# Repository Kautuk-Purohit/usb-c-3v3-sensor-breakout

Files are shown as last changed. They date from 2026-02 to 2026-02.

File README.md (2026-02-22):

# KiCad PCB Project

A fabrication ready PCB designed as a portfolio project.  
Includes a full schematic and PCB layout, verified with ERC (Electrical Rules Check) and DRC (Design Rules Check), and validated Gerbers and drills in Gerber Viewer.

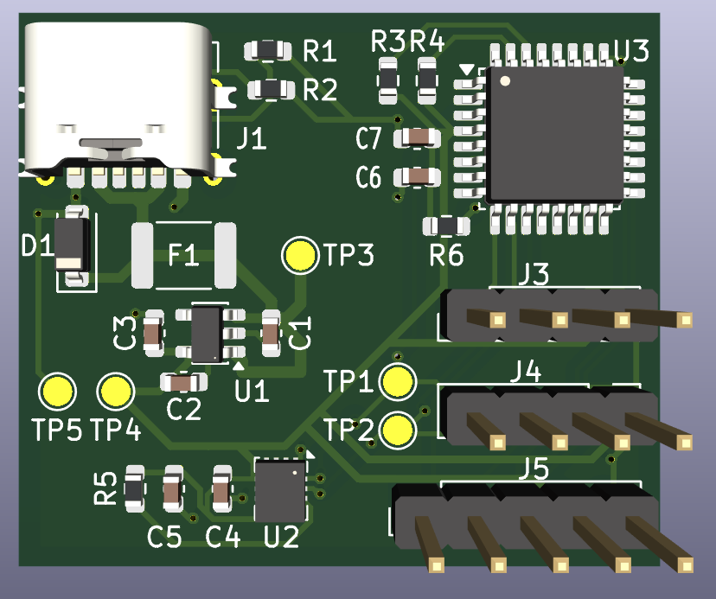
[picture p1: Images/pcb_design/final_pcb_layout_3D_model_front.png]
PCB 3D View


---

## Table of Contents
- [Overview](#overview)
- [Key Features](#key-features)
- [Project Status](#project-status)
- [Repo Structure](#repo-structure)
- [Verification](#verification)
- [Manufacturing Outputs](#manufacturing-outputs)
- [How to Open](#how-to-open)
- [Key Images](#images)
- [Next Improvements](#next-improvements)

---

## Overview
This project demonstrates an end to end PCB workflow:

schematic design → layout and routing → design rule checks → manufacturing outputs

The goal is to show practical board design skills (power, interfaces, layout, manufacturability) 

---

## Key Features
- USB power input with on board 3.3V regulation
- Microcontroller based system design
- I2C (Inter Integrated Circuit) sensor bus (IMU)
- Labeled connectors and test points for bring up
- Ground plane implemented
- Manufacturing package generated (Gerbers + PTH and NPTH drills)
- BOM and pick and place exported for assembly readiness

---

## Project Status
- [x] Placement and routing complete
- [x] Ground plane set
- [x] ERC clean
- [x] DRC clean
- [x] 3D view checked for footprint consistency
- [x] Gerbers generated
- [x] Drill files generated (PTH + NPTH)
- [x] Gerbers and drills verified in Gerber Viewer
- [X] BOM committed
- [X] Pick and place committed

---

## Repo Structure
```text
.
├── kicad/                     # KiCad schematic + PCB
├── manufacturing/
│   ├── gerbers/               # plotted Gerbers
│   ├── drill/                 # Excellon drills (PTH + NPTH)
│   ├── bom/                   # BOM exports
│   ├── assembly/              # pick and place / position outputs
│   └── release/               # upload ready ZIP(s)
└── images/                    
│   ├── manufacturing/         # Manufacturing related pictures
│   ├── pcb_design/            # PCB Design pictures
│   ├── schematic/             # Schematic related pictures
```
---

## Verification
- ERC (Electrical Rules Check): clean
- DRC (Design Rules Check): clean
- 3D Viewer: checked for footprint consistency
- Gerber Viewer: verified copper, mask, silkscreen, outline, and drill alignment (PTH + NPTH)

---

## Manufacturing Outputs
### Fabrication package (upload ready)
[RELEASE FILE](manufacturing/release/PCB_RELEASE_GERBER_DRILL.zip)

### Assembly data
- [BOM](manufacturing/bom/usb_c_sensor_breakout.csv)
- [Pick and Place POS Files](manufacturing/assembly)

---

## How to Open
1. Install KiCad (project created in KiCad 9.0).
2. Open the project in `kicad/`.
3. Review:
   - Schematic (`.kicad_sch`)
   - PCB layout (`.kicad_pcb`)
   - 3D Viewer
4. Manufacturing outputs are in `manufacturing/`.

---

## Images

### PCB 3D front:
PCB 3D Front

### PCB 3D back:
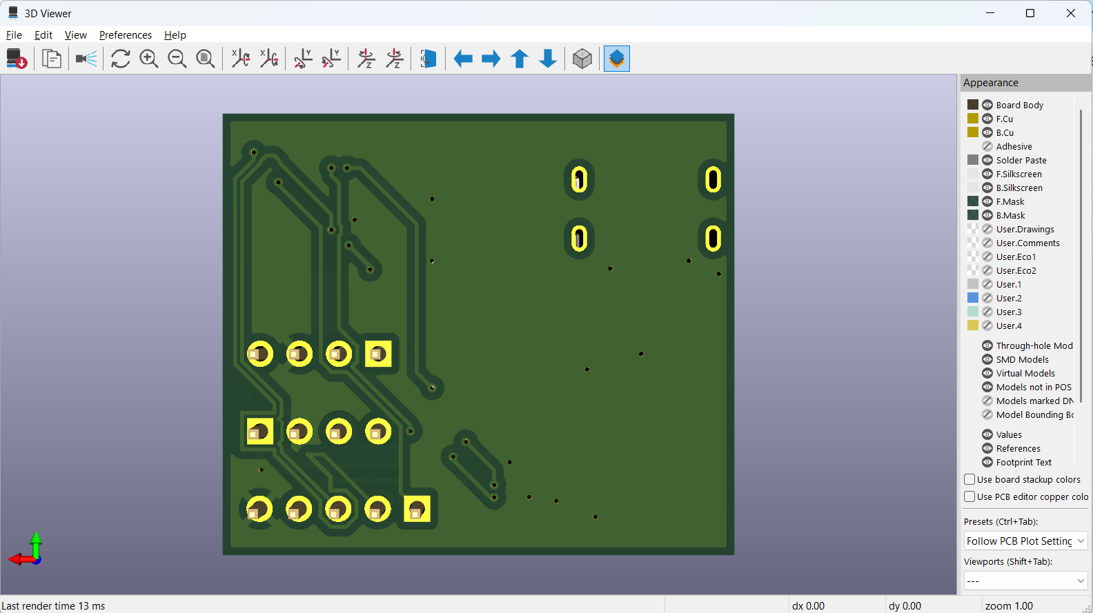
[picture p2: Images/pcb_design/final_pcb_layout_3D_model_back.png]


### PCB Final Layout: 
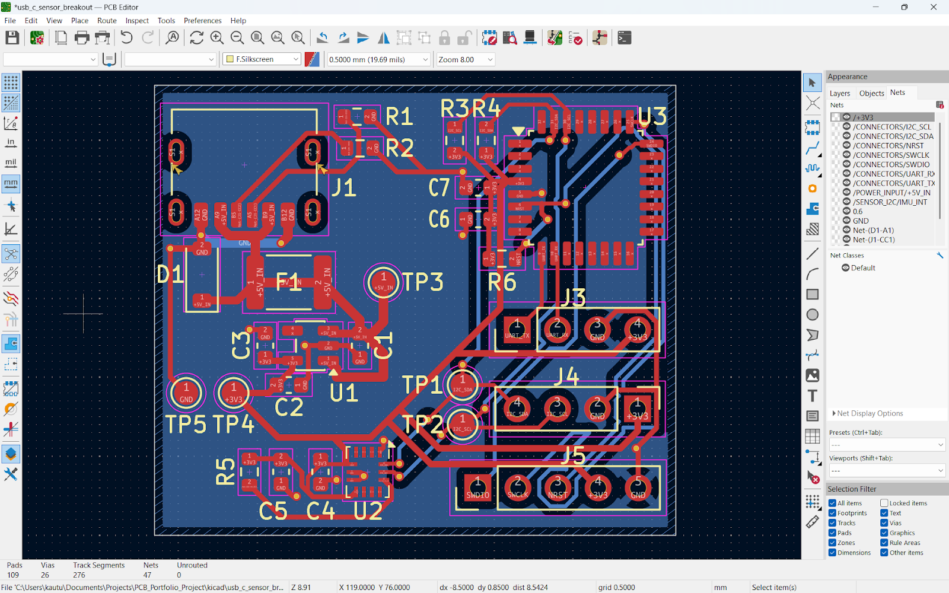
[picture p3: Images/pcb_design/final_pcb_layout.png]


### Gerber overlay: 
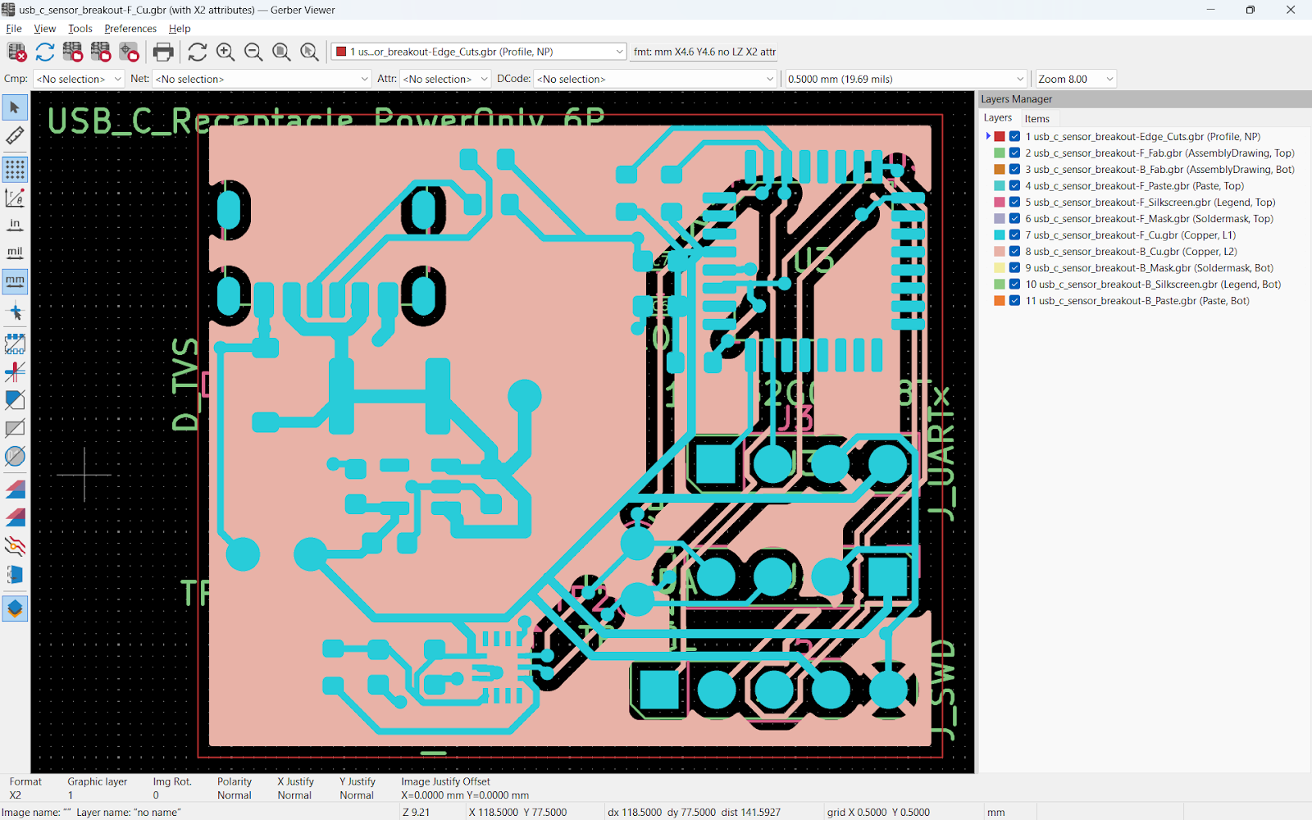
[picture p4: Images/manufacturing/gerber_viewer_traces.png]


### Drill overlay (PTH + NPTH): 
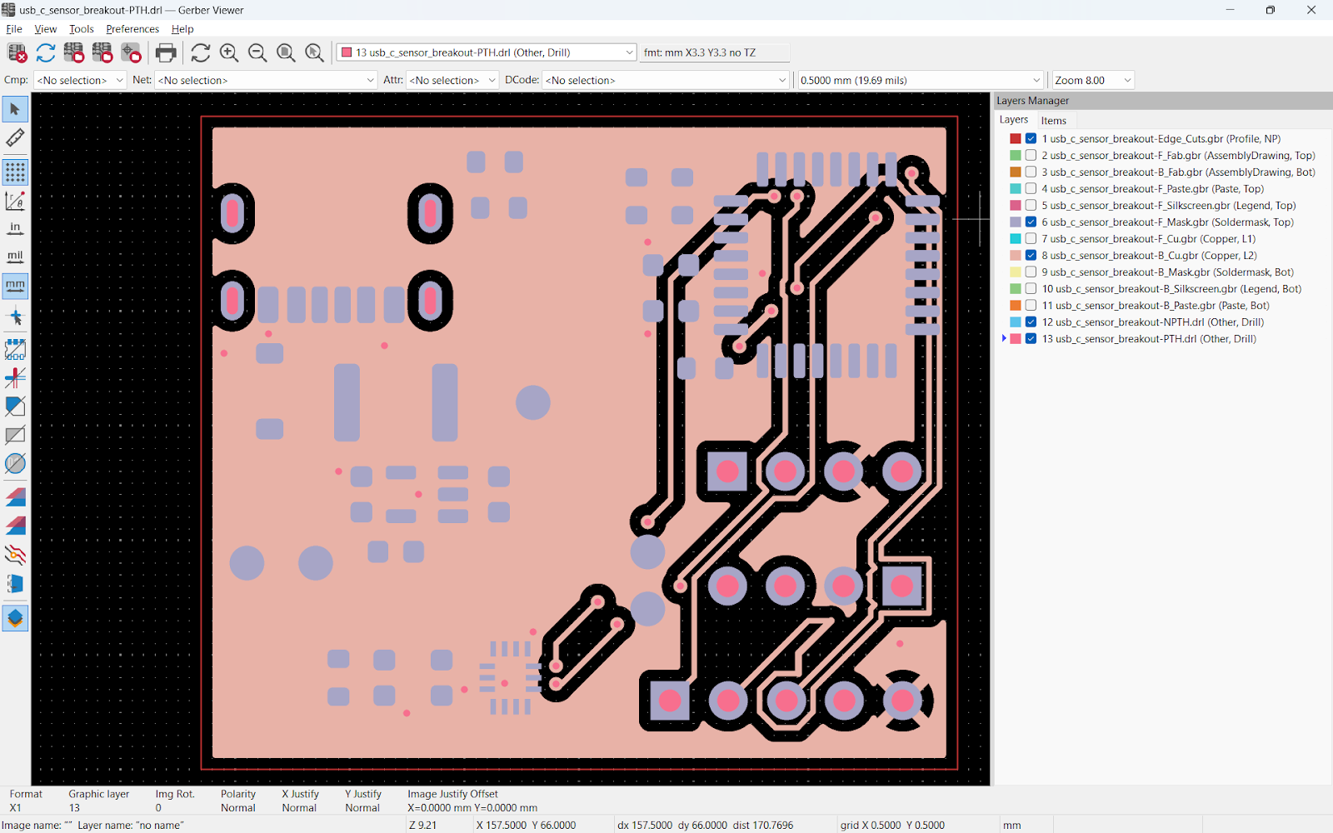
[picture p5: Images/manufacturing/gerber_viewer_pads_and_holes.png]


---

## Next Improvements
In a future revision:
- Add fiducials
- Add additional ESD protection (eg. for external connectors)
- Improve silkscreen placement and reference readability
- Adding NPTH drills (mounting holes) for realistic usage

---

## License
All Rights Reserved.

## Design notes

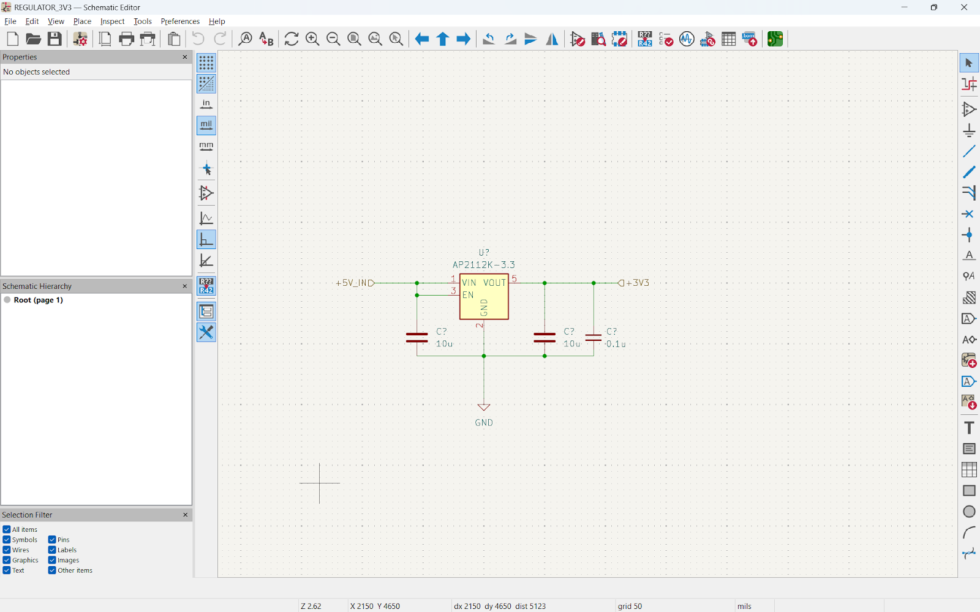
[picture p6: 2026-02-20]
Images/schematic/regulator_iteration1.png

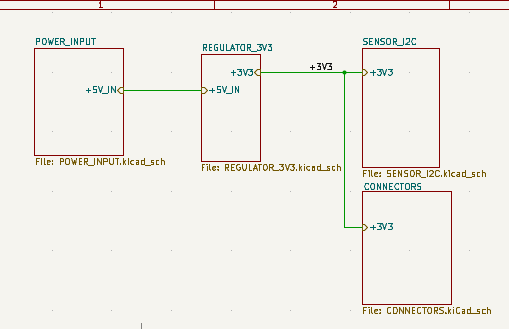
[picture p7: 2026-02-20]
Images/schematic/top_level_iteration1.png

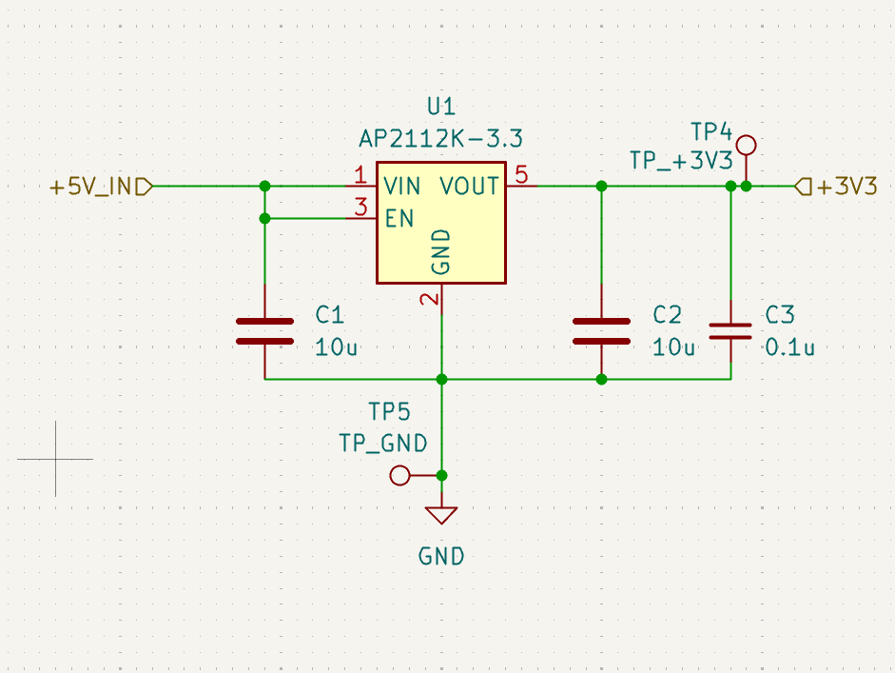
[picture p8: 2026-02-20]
Images/schematic/final_regulator_schematic.png

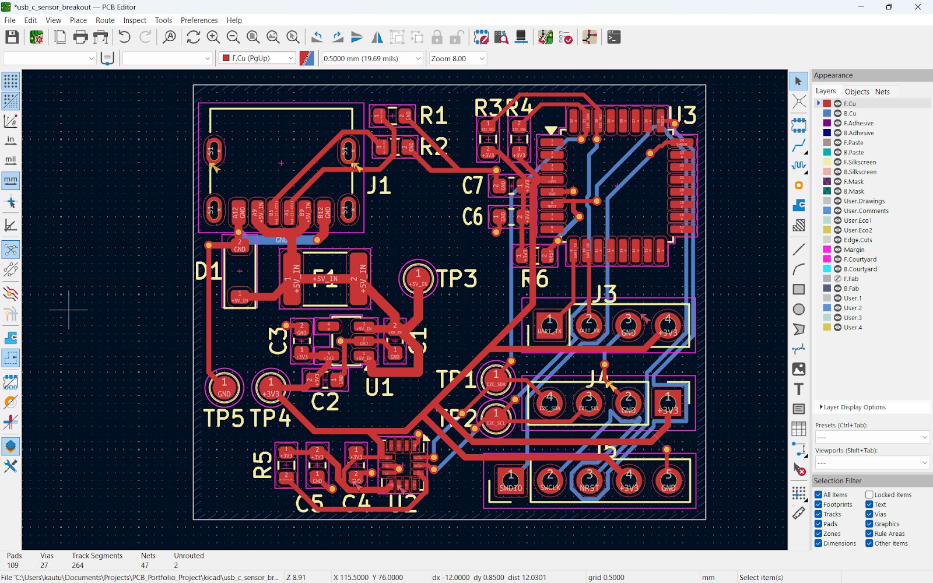
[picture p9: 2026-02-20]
Images/pcb_design/iteration1_traces.png

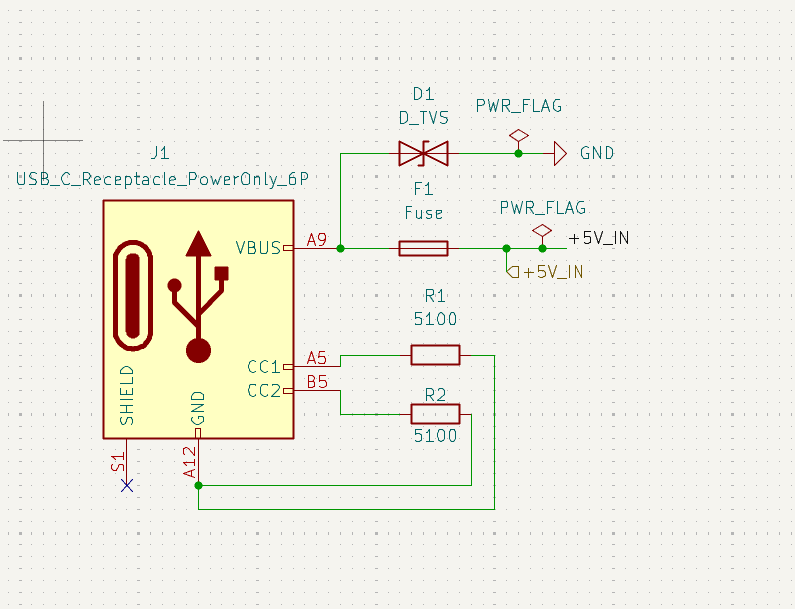
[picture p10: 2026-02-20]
Images/schematic/power_input_iteration1.png

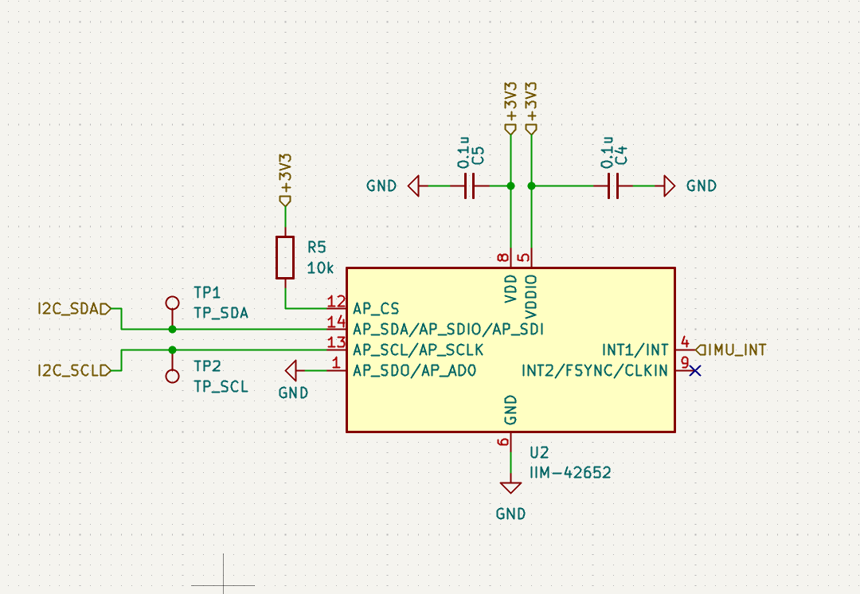
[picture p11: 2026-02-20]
Images/schematic/final_sensor_schematic.png

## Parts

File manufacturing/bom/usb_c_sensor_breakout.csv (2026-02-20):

Reference | Qty | Value | DNP | Exclude from BOM | Exclude from Board | Footprint | Datasheet
C1,C2,C6 | 3 | 10u |  |  |  | Capacitor_SMD:C_0603_1608Metric | ~
C3,C4,C5,C7 | 4 | 0.1u |  |  |  | Capacitor_SMD:C_0603_1608Metric | ~
D1 | 1 | D_TVS |  |  |  | Diode_SMD:D_SOD-123 | ~
F1 | 1 | Fuse |  |  |  | Fuse:Fuse_1812_4532Metric | ~
J1 | 1 | USB_C_Receptacle_PowerOnly_6P |  |  |  | Connector_USB:USB_C_Receptacle_HRO_TYPE-C-31-M-17 | https://www.usb.org/sites/default/files/documents/usb_type-c.zip
J3 | 1 | J_UART |  |  |  | Connector_PinHeader_2.54mm:PinHeader_1x04_P2.54mm_Vertical | ~
J4 | 1 | J_I2C_EXP |  |  |  | Connector_PinHeader_2.54mm:PinHeader_1x04_P2.54mm_Vertical | ~
J5 | 1 | J_SWD |  |  |  | Connector_PinHeader_2.54mm:PinHeader_1x05_P2.54mm_Vertical | ~
R1,R2 | 2 | 5100 |  |  |  | Resistor_SMD:R_0603_1608Metric | ~
R3,R4 | 2 | 4.7k |  |  |  | Resistor_SMD:R_0603_1608Metric | ~
R5,R6 | 2 | 10k |  |  |  | Resistor_SMD:R_0603_1608Metric | ~
TP1 | 1 | TP_SDA |  |  |  | TestPoint:TestPoint_Pad_D1.5mm | ~
TP2 | 1 | TP_SCL |  |  |  | TestPoint:TestPoint_Pad_D1.5mm | ~
TP3 | 1 | TP_+5V_IN |  |  |  | TestPoint:TestPoint_Pad_D1.5mm | ~
TP4 | 1 | TP_+3V3 |  |  |  | TestPoint:TestPoint_Pad_D1.5mm | ~
TP5 | 1 | TP_GND |  |  |  | TestPoint:TestPoint_Pad_D1.5mm | ~
U1 | 1 | AP2112K-3.3 |  |  |  | Package_TO_SOT_SMD:SOT-23-5 | https://www.diodes.com/assets/Datasheets/AP2112.pdf
U2 | 1 | IIM-42652 |  |  |  | Package_LGA:Bosch_LGA-14_3x2.5mm_P0.5mm | https://invensense.tdk.com/wp-content/uploads/2021/01/ds-000440_iim-42652-datasheet.pdf
U3 | 1 | STM32G031K8Tx |  |  |  | Package_QFP:LQFP-32_7x7mm_P0.8mm | https://www.st.com/resource/en/datasheet/stm32g031k8.pdf

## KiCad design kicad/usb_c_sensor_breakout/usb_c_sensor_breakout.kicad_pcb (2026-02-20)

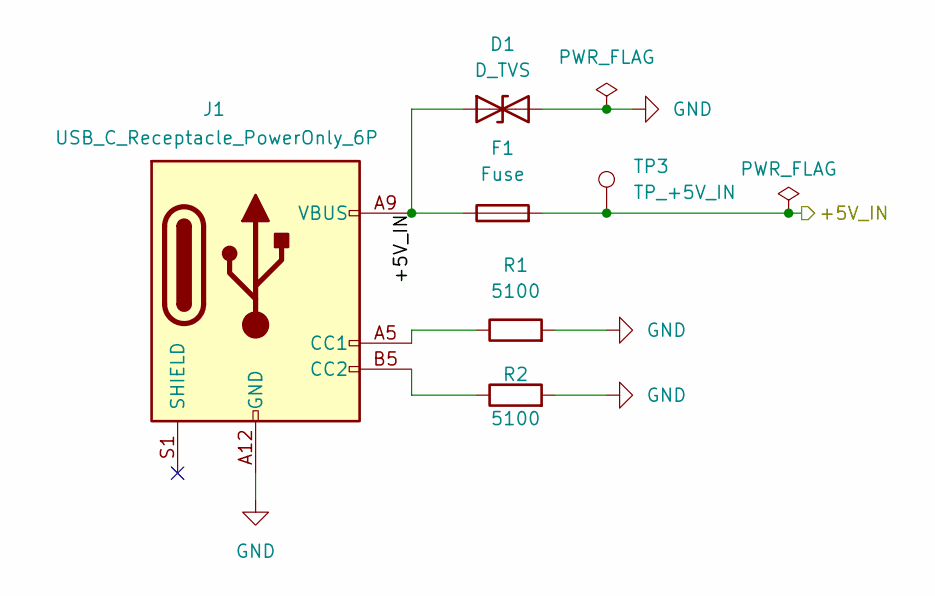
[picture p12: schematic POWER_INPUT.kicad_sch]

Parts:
D1: D_TVS; D_SOD-123
F1: Fuse; Fuse_1812_4532Metric
J1: USB_C_Receptacle_PowerOnly_6P; USB_C_Receptacle_HRO_TYPE-C-31-M-17
R1, R2: 5100; R_0603_1608Metric
TP3: TP_+5V_IN; TestPoint_Pad_D1.5mm

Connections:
/POWER_INPUT/+5V_IN: D1.1 (A1), F1.1, F1.2, J1.A9 (VBUS), J1.B9 (VBUS), TP3.1; also elsewhere on the board
GND: D1.2 (A2), J1.A12 (GND), J1.B12 (GND), R1.2, R2.2; also elsewhere on the board
unnamed: J1.A5 (CC1), R1.1
unnamed: J1.B5 (CC2), R2.1

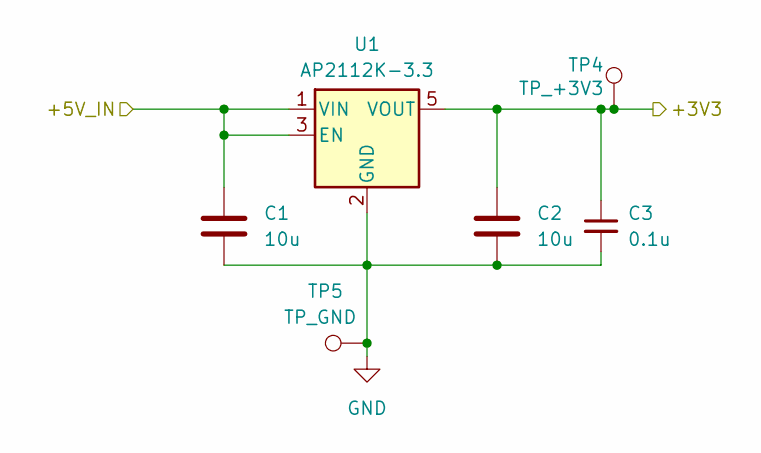
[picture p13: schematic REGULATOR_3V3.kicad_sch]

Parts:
C1, C2: 10u; C_0603_1608Metric
C3: 0.1u; C_0603_1608Metric
TP4: TP_+3V3; TestPoint_Pad_D1.5mm
TP5: TP_GND; TestPoint_Pad_D1.5mm
U1: AP2112K-3.3; SOT-23-5

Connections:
/+3V3: C2.2, C3.1, TP4.1, U1.5 (VOUT); also elsewhere on the board
/POWER_INPUT/+5V_IN: C1.2, U1.1 (VIN), U1.3 (EN); also elsewhere on the board
GND: C1.1, C2.1, C3.2, TP5.1, U1.2 (GND); also elsewhere on the board

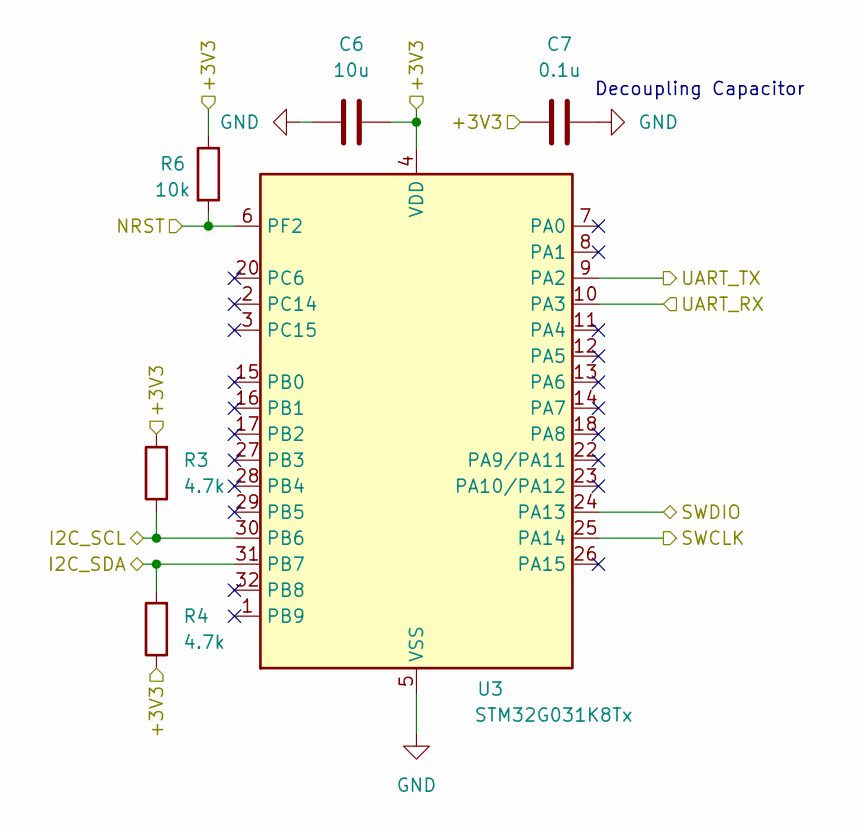
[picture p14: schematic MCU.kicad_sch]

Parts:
C6: 10u; C_0603_1608Metric
C7: 0.1u; C_0603_1608Metric
R3, R4: 4.7k; R_0603_1608Metric
R6: 10k; R_0603_1608Metric
U3: STM32G031K8Tx; LQFP-32_7x7mm_P0.8mm

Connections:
/+3V3: C6.2, C7.1, R3.2, R4.1, R6.1, U3.4 (VDD); also elsewhere on the board
/CONNECTORS/I2C_SCL: R3.1, U3.30 (PB6); also elsewhere on the board
/CONNECTORS/I2C_SDA: R4.2, U3.31 (PB7); also elsewhere on the board
/CONNECTORS/NRST: R6.2, U3.6 (PF2); also elsewhere on the board
/CONNECTORS/SWCLK: U3.25 (PA14); also elsewhere on the board
/CONNECTORS/SWDIO: U3.24 (PA13); also elsewhere on the board
/CONNECTORS/UART_RX: U3.10 (PA3); also elsewhere on the board
/CONNECTORS/UART_TX: U3.9 (PA2); also elsewhere on the board
GND: C6.1, C7.2, U3.5 (VSS); also elsewhere on the board

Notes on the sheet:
Decoupling Capacitor

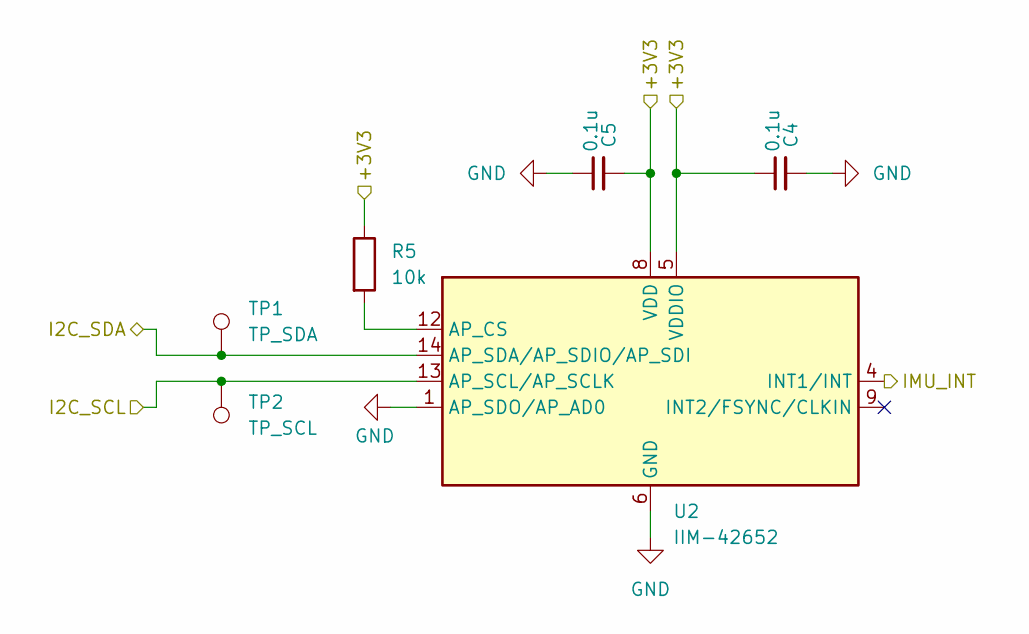
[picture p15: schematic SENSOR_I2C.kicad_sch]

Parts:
C4, C5: 0.1u; C_0603_1608Metric
R5: 10k; R_0603_1608Metric
TP1: TP_SDA; TestPoint_Pad_D1.5mm
TP2: TP_SCL; TestPoint_Pad_D1.5mm
U2: IIM-42652; Bosch_LGA-14_3x2.5mm_P0.5mm

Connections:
/+3V3: C4.1, C5.2, R5.1, U2.5 (VDDIO), U2.8 (VDD); also elsewhere on the board
/CONNECTORS/I2C_SCL: TP2.1, U2.13 (AP_SCL/AP_SCLK); also elsewhere on the board
/CONNECTORS/I2C_SDA: TP1.1, U2.14 (AP_SDA/AP_SDIO/AP_SDI); also elsewhere on the board
/SENSOR_I2C/IMU_INT: U2.4 (INT1/INT)
GND: C4.2, C5.1, U2.1 (AP_SDO/AP_AD0), U2.6 (GND), U2.7 (GND); also elsewhere on the board
unnamed: R5.2, U2.12 (AP_CS)

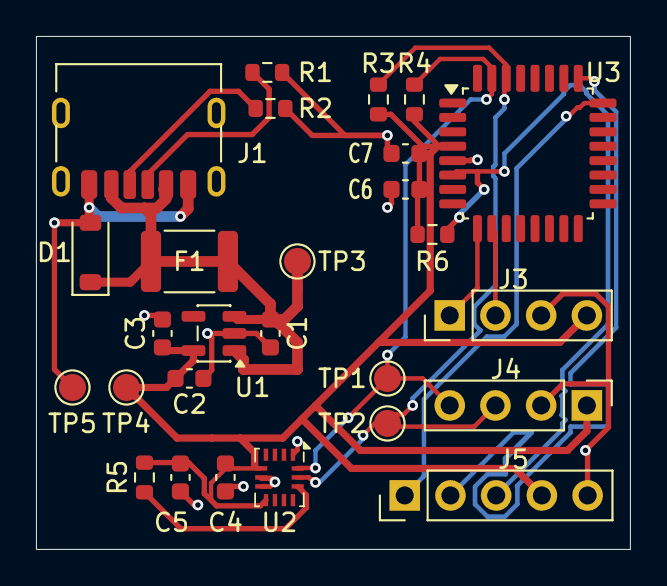
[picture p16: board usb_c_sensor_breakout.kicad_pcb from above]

Board: 2 copper layers, 33.0 x 28.5 mm, 27 parts (0 on the bottom side), 13 nets.

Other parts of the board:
J3: J_UART; PinHeader_1x04_P2.54mm_Vertical
J4: J_I2C_EXP; PinHeader_1x04_P2.54mm_Vertical
J5: J_SWD; PinHeader_1x05_P2.54mm_Vertical

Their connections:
/+3V3: J3.4, J4.1, J5.4; also elsewhere on the board
/CONNECTORS/I2C_SCL: J4.3; also elsewhere on the board
/CONNECTORS/I2C_SDA: J4.4; also elsewhere on the board
/CONNECTORS/NRST: J5.3; also elsewhere on the board
/CONNECTORS/SWCLK: J5.2; also elsewhere on the board
/CONNECTORS/SWDIO: J5.1; also elsewhere on the board
/CONNECTORS/UART_RX: J3.2; also elsewhere on the board
/CONNECTORS/UART_TX: J3.1; also elsewhere on the board
GND: J3.3, J4.2, J5.5; also elsewhere on the board

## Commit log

2026-02-05 Day 0: project structure and KiCad project
    [usb_c_sensor_breakout.kicad_pcb, usb_c_sensor_breakout.kicad_sch]
2026-02-14 commit2: usbc + regulator + i2c pullups + sensor header + testpoint
    [CONNECTORS.kicad_sch, POWER_INPUT.kicad_sch, REGULATOR_3V3.kicad_sch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]
2026-02-15 Commit3: Regulators + Top-level + I2C sensor upgrade
    [CONNECTORS.kicad_sch, POWER_INPUT.kicad_sch, REGULATOR_3V3.kicad_sch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]
2026-02-15 Commit 4: Updated annotation + footprints
    [CONNECTORS.kicad_sch, POWER_INPUT.kicad_sch, REGULATOR_3V3.kicad_sch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]
2026-02-15 Commit 5: MCU + Final Schematic Touches + Labelling + USBc fix
    [CONNECTORS.kicad_sch, MCU.kicad_sch, POWER_INPUT.kicad_sch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]
2026-02-20 Commit 6: Finished PCB + Updated Schematic
    [CONNECTORS.kicad_sch, MCU.kicad_sch, POWER_INPUT.kicad_sch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]
2026-02-20 Commit 7: Fab outputs (Gerbers + Drills) - Verified in Gerber Viewer
    [usb_c_sensor_breakout-B_Cu.gbr, usb_c_sensor_breakout-B_Fab.gbr, usb_c_sensor_breakout-B_Mask.gbr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]
2026-02-20 Commit 8: BOM + pick-and-place outputs
    [usb_c_sensor_breakout.csv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]
